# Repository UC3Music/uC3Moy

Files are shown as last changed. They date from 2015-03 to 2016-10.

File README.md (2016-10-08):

uC3Moy
======

UC3Music-e version of the CMoy pocket headphone amplifier (originally designed by Chu Moy )

Designed to fit in to a Smint* can.
Smint sweets can inner dimensions: 69mm x 36mm x 17mm. Outer dimensions: 77mm x 40mm x 21mm.

Designed to work on a single 6LR61 9V battery (alcaline or rechargeable). Draws about 8mA of current at regular listening levels (13mA at full output). Lithium technology coming soon.

It might get loud, use responsibly.

<p align="center">
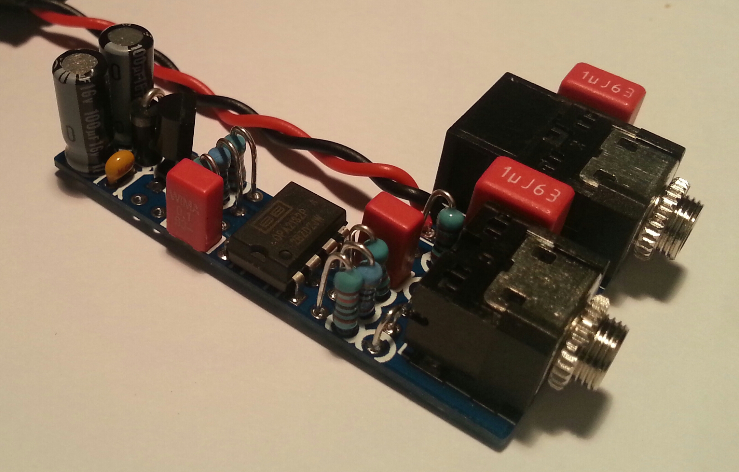
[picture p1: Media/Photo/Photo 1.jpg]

</p>

>*Smint is a mint sweet similar to Wrigley's Eclipse

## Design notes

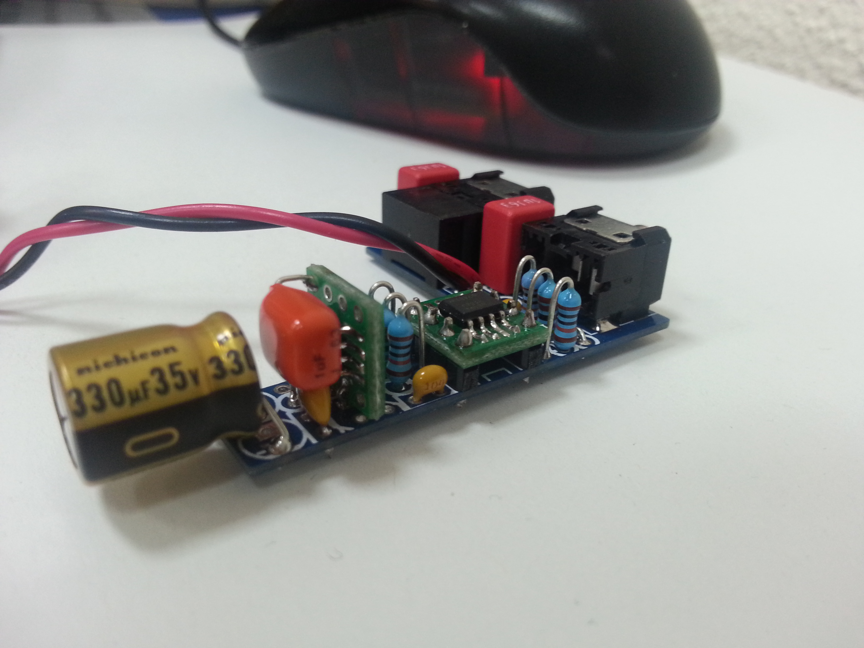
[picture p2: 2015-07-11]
Media/Photo/Power Supply Mod.jpg

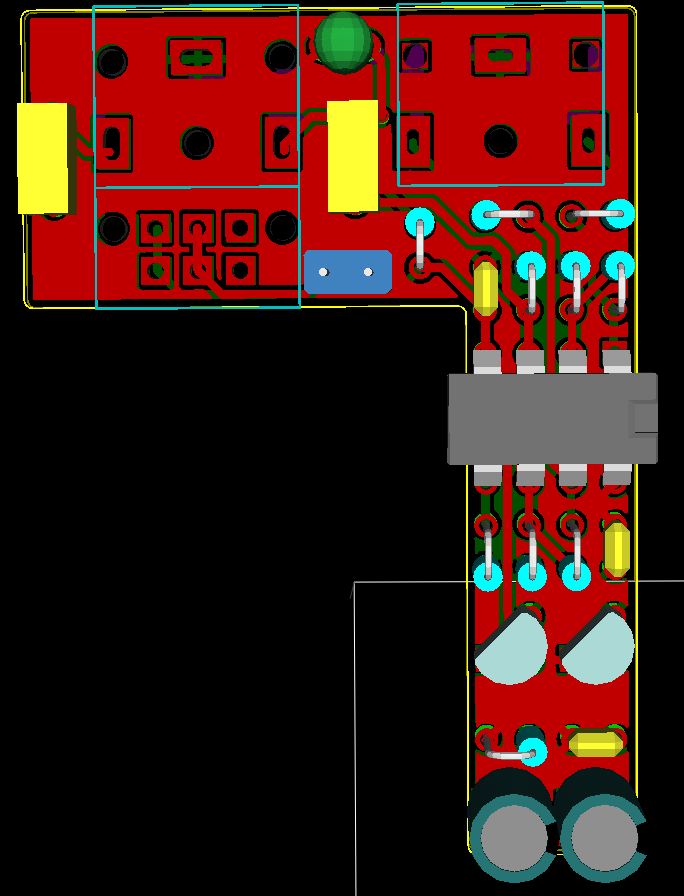
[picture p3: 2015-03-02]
Media/Simulated Top View 2.JPG

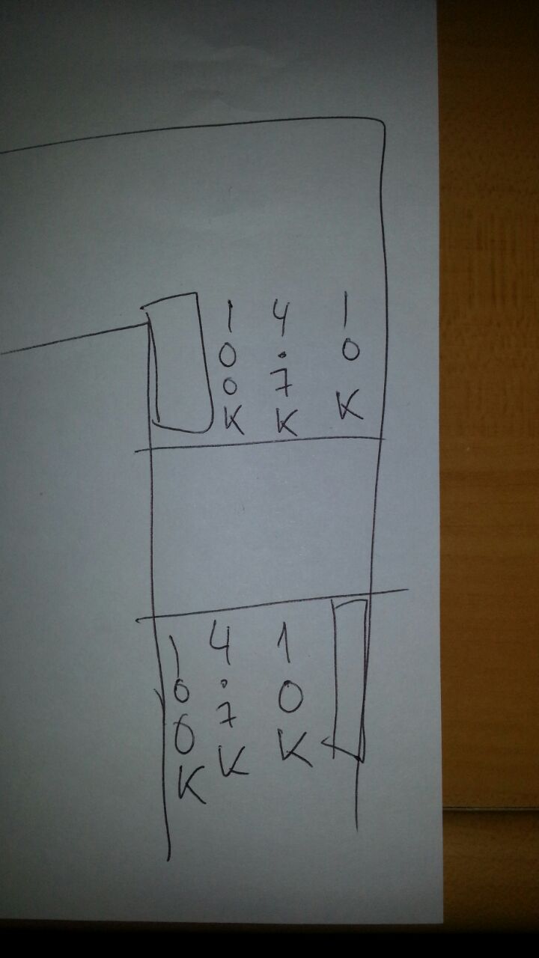
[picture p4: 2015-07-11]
Media/Resistors Position.jpg

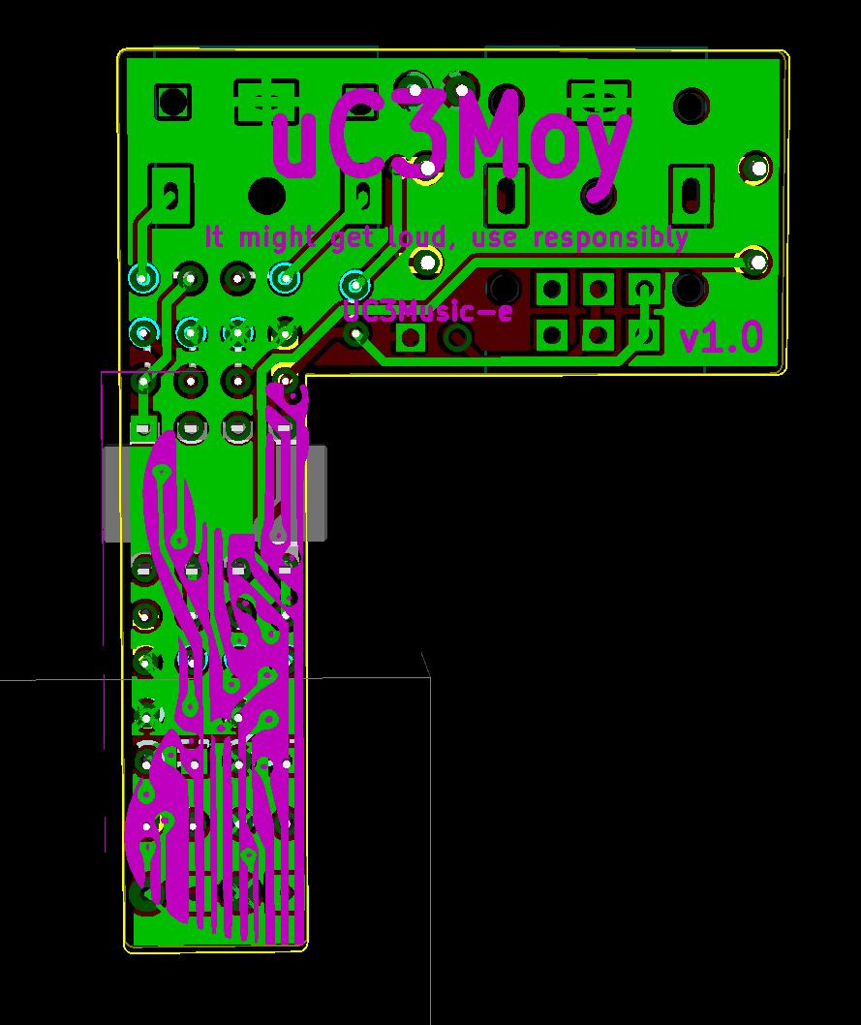
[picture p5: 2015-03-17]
Media/Simulated Back View.JPG

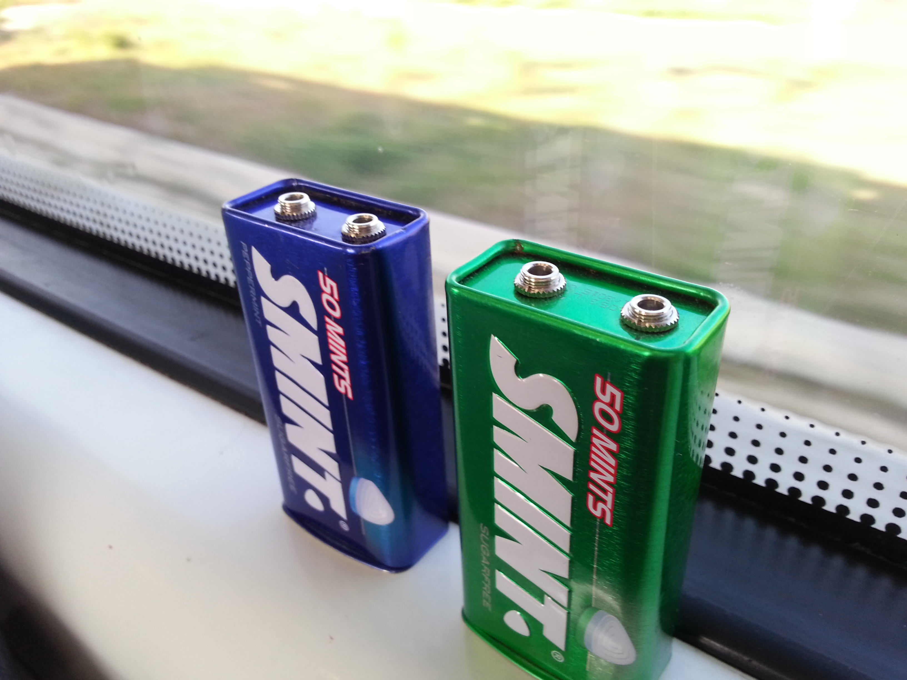
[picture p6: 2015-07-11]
Media/Photo/UC3Moy is traveling.jpg

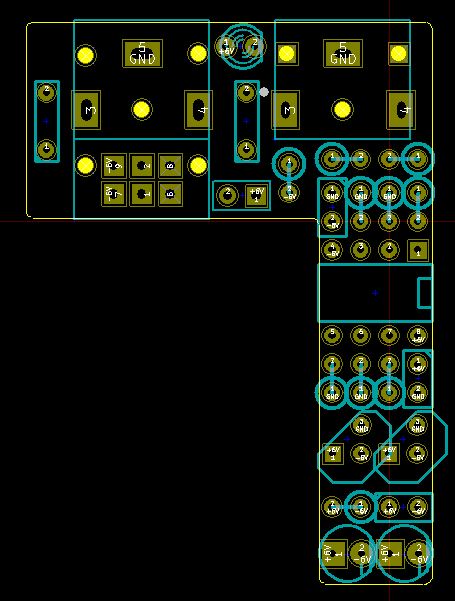
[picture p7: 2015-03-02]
Media/Simulated Top View.JPG

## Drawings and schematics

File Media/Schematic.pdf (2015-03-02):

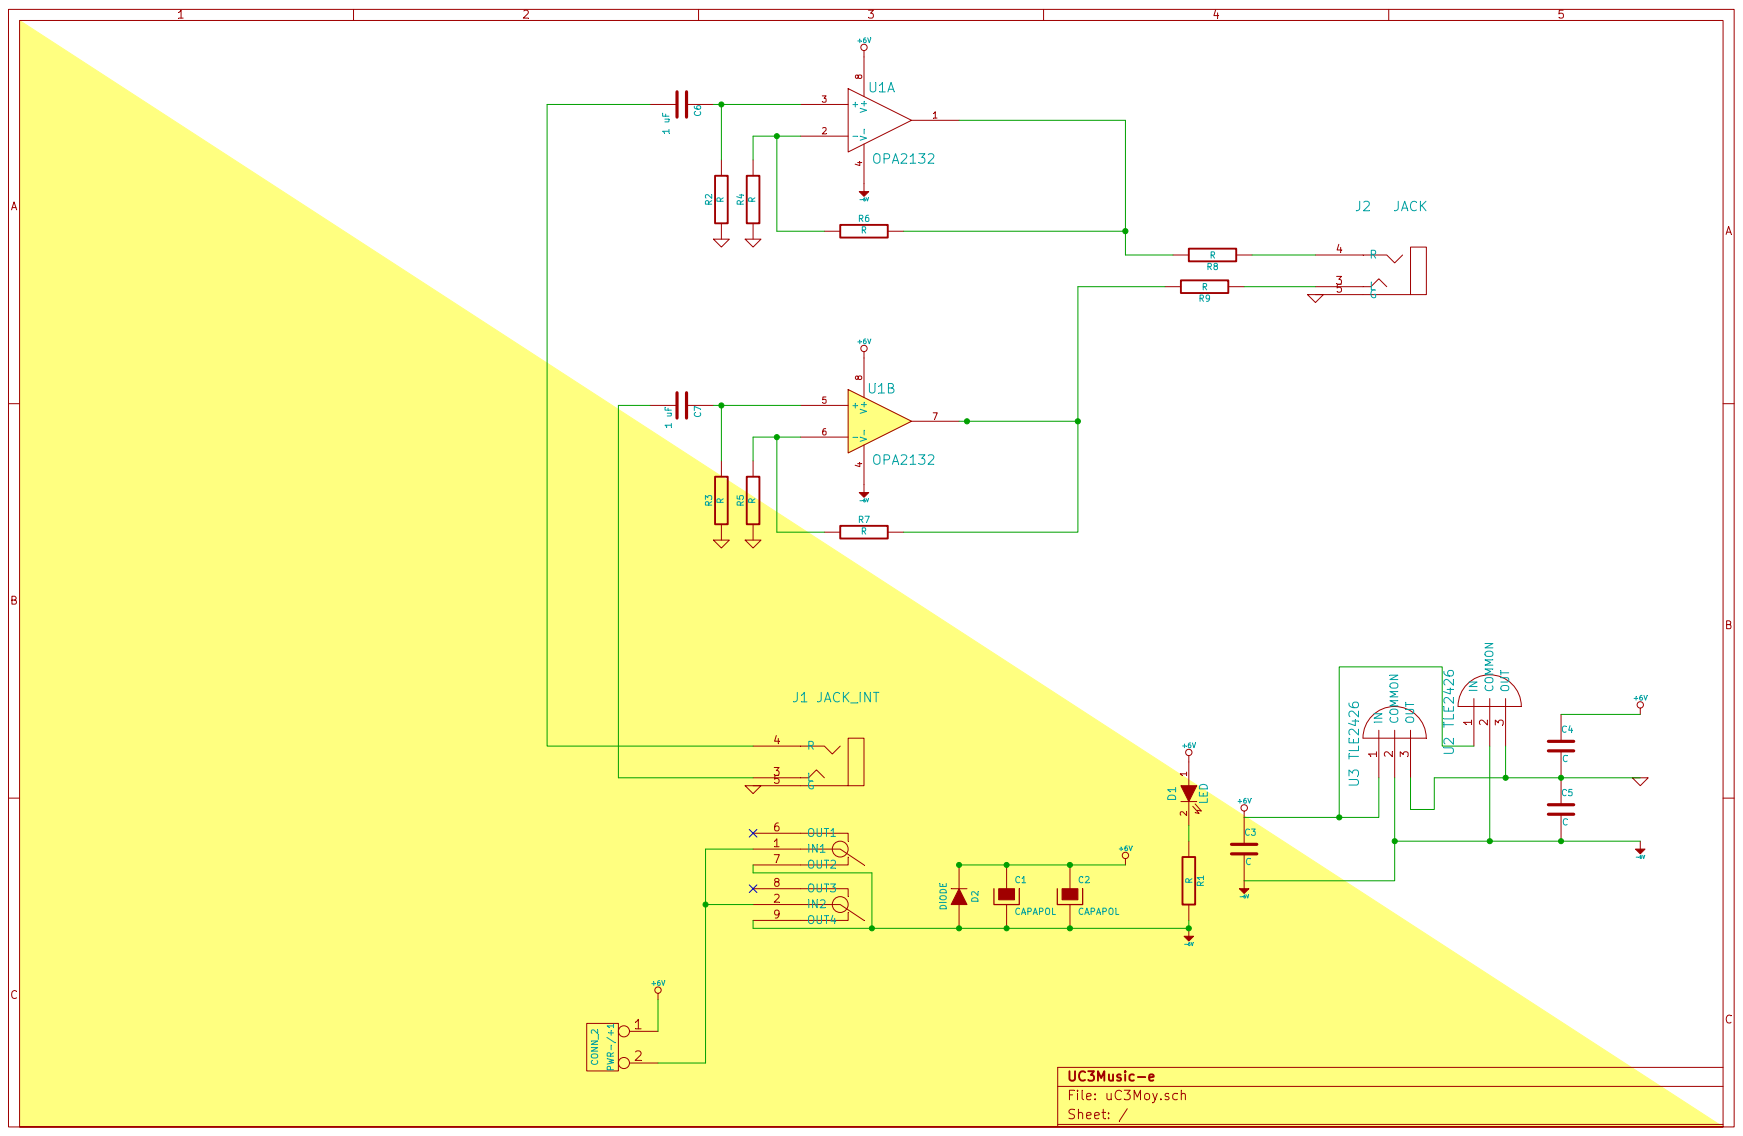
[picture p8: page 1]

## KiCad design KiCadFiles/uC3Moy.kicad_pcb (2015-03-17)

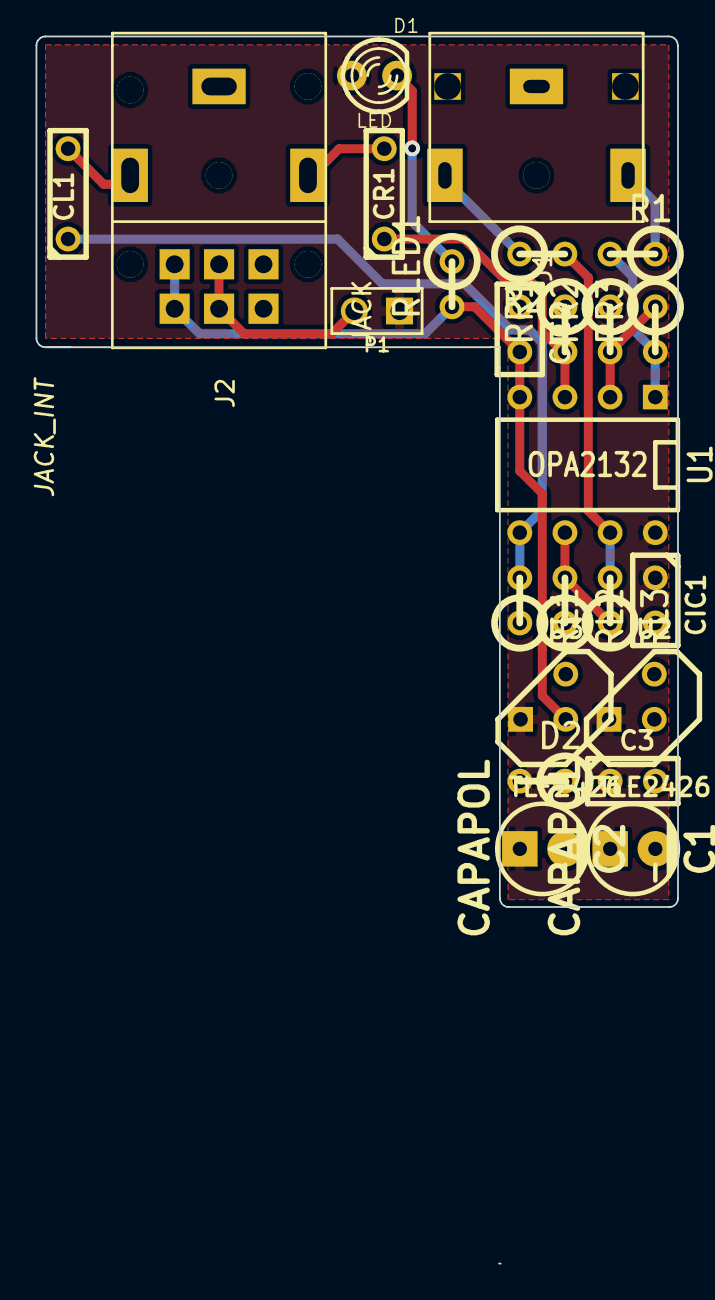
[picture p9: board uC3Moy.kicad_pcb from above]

Board: 2 copper layers, 36.1 x 49.0 mm, 24 parts (0 on the bottom side), 15 nets.

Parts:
C1, C2: CAPAPOL; CP_5x11mm
C3: C; C1
CIC1, CIC2: C; C1
CL1: 1 uF; C2
CR1: 1 uF; C2
D1: LED; LED-3MM
D2: DIODE; R1
J1: JACK; jack
J2: JACK_INT; jackint
P1: CONN_2; PIN_ARRAY_2X1
R1, R2: R; R1
RL1, RL2, RL3: R; R1
RLED1: R; R1
RR1, RR2, RR3: R; R1
U1: OPA2132; DIP-8__300
U2, U3: TLE2426; TO92

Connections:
+6V: C1.1, C2.1, C3.1, CIC1.1, D1.1, D2.2, P1.1, U1.8, U2.1, U3.1
-6V: C1.2, C2.2, C3.2, CIC2.2, D2.1, J2.7, J2.9, RLED1.2, U1.4, U2.2, U3.2
GND: CIC1.2, CIC2.1, J1.5, J2.5, RL1.1, RL2.1, RR1.1, RR2.1, U2.3, U3.3
unnamed: RL2.2, RL3.1, U1.6
unnamed: R2.2, RL3.2, U1.7
unnamed: CR1.2, J2.4
unnamed: CL1.2, J2.3
unnamed: CL1.1, RL1.2, U1.5
unnamed: J2.1, J2.2, P1.2
unnamed: D1.2, RLED1.1
unnamed: CR1.1, RR1.2, U1.3
unnamed: RR2.2, RR3.1, U1.2
unnamed: J1.4, R1.1
unnamed: R1.2, RR3.2, U1.1
unnamed: J1.3, R2.1

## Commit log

2014-11-22 Added schematic (without connectors).
    [uC3Moy.sch]
2015-03-02 Commit subiendo el diseño principal
    [uC3Moy.sch, uC3MoyPINRS.kicad_pcb]
2015-03-02 General UPLOAD
    PCB folder created.
    >Media folder containing .jpg images of PCB created.
    >KiCadFiles folder containing KiCad files of PCB created.
    >gerber folder containing gerber files of PCB created.
    A .pdf file containing a drawing of the schematic added.
    [uC3Moy-B_Cu.gbl, uC3Moy-B_Mask.gbs, uC3Moy-B_Paste.gbp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]
2015-03-06 README revision
    [uC3Moy.sch, uC3MoyPINRS.kicad_pcb]
2015-03-06 Schematic on .pdf added to Media folder
2015-03-14 Modified lenght to fit under 50x50mm boards
    [uC3Moy.kicad_pcb]
2015-03-15 redo gerbers
    [uC3Moy-B_Cu.gbl, uC3Moy-B_Mask.gbs, uC3Moy-B_SilkS.gbo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]
2015-03-15 Silkscreen upgrades
    [uC3Moy.kicad_pcb]
2015-03-16 guitar logo added to back silkscreen
    [uC3Moy.kicad_pcb]
2015-03-17 Updates in bottom silkescreen
    [uC3Moy.kicad_pcb]
2015-03-17 updated gerbers
    [uC3Moy-B_Cu.gbl, uC3Moy-B_Mask.gbs, uC3Moy-B_SilkS.gbo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]
2015-03-19 substracted soldermask from silkscreen
    [uC3Moy-B_Cu.gbl, uC3Moy-B_Mask.gbs, uC3Moy-B_SilkS.gbo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]
2015-03-19 v0.1 gerber files sended to SeeedStudio
    [uC3Moy-B_Paste.gbp, uC3Moy-F_Paste.gtp]
2015-11-05 Ready to rock!
    [uC3Moy-B_Cu.gbl, uC3Moy-B_Mask.gbs, uC3Moy-B_SilkS.gbo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]
2015-11-05 uploaded gerber.zip
2015-11-05 Ready to rock
    [uC3Moy.kicad_pcb]
2015-11-13 Big and spaaaaacy oval pads. Ready to rock. Gerbers sent to PCBWay. V2.0 finished
    [uC3Moy-B_Cu.gbl, uC3Moy-B_Mask.gbs, uC3Moy-B_SilkS.gbo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]
2016-10-08 Updated README
    Me equivoqué en una letra, y qué?
    Pues que tiene que quedar decoroso, leñe!
